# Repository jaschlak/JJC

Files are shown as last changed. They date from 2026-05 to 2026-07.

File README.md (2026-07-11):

# JJC V1

Jordan's Juggle Clubs V1 is a 3D-printing and Fusion scripting project for designing a simple juggling club around a rigid 1/2 inch dowel rod spine.

V2 is started in `JJC_v2/` as a Delphin-style, dowel-core practice club targeting a 502 mm length.

V3 is started in `JJC_v3/` as a hollow-body revision focused on lowering the estimated center of rotation compared with V2.

The printed club version folders, `JJC_v1/`, `JJC_v2/`, and `JJC_v3/`, are mechanical prototypes. They intentionally have no LEDs, microcontrollers, batteries, or diffusers.

Electronics prototyping is tracked separately in `electronics/`. Its `v1/` folder means electronics prototype v1, not printed club V1. It starts with ESP32 and WS2812B LED bench tests before any final club integration.

## Design Direction

- Main structure uses a 1/2 inch dowel rod.
- Printed parts fit around or onto the dowel.
- Most printed parts are expected to be TPU.
- The club will be designed in sections because the printer build volume is limited.
- Each part gets a numbered resource spec and, when useful, a matching Fusion script.

## Balance Estimates

Center of rotation is documented as the estimated balance point along the club axis, measured from the knob end.

```text
V1 prototype estimate: 209.1 mm from knob, 50.6% of 413 mm prototype length
V2 estimate: 272.1 mm from knob, 54.2% of 502 mm length
V3 target: 255-265 mm from knob, 51-53% of 502 mm length
V3 estimate: 260.6 mm from knob, 51.9% of 502 mm length
```

These are calculated estimates using documented geometry and material density assumptions. The real value should be checked by balancing the assembled club on a pencil or round rod.

## Printer

Current printer:

```text
Creality Ender 3 V3 SE
Build volume: 220 x 220 x 250 mm
Direct extruder: suitable for TPU
```

TPU should be printed slower than the advertised maximum printer speed.

## Folder Layout

```text
Resources/
  0_parts_list.md
  1_dowel_rod_spec.md
  2_dowel_centering_ring_spec.md
  3_handle_sleeve_spec.md
  4_knob_cap_spec.md
  Images/

Fusion/
  JJCv1_1_dowel_rod/
  JJCv1_2_dowel_centering_ring/
  JJCv1_3_handle_sleeve/
  JJCv1_4_knob cap/
  JJCv1_9_full_club_assembly/

../electronics/
  README.md
  v1/
    README.md
    parts_list.md
    assembly_guide.md
    esp32_programming.md
```

## Current Parts

### 1. Dowel Rod

The rigid spine of the club.

```text
1/2 inch = 12.7 mm
```

There is a Fusion script for creating the dowel rod as its own reference part.

Measure the actual dowel before finalizing printed fit dimensions.

### 2. Dowel Centering Ring

A washer-like part that slides over the dowel and helps keep it centered inside the future hollow club body.

### 3. Handle Sleeve

A hollow TPU grip sleeve that slides over the dowel.

### 4. Knob Cap

A TPU end cap with a blind socket for the dowel. This forms the rounded handle-end bumper.

### 9. Full Club Assembly

A Fusion assembly script creates the dowel rod, handle sleeve, knob cap, body-to-handle collar, lower body shell, upper body shell, and nose cap as separate components in one design.

## Fusion Workflow

Fusion scripts must be run from inside Autodesk Fusion, not from normal desktop Python.

To run a script:

1. Open Fusion.
2. Create or open a design.
3. Go to **Utilities > Add-Ins > Scripts and Add-Ins**.
4. Add the relevant script folder if it is not already listed.
5. Select the script.
6. Click **Run**.

Do not run the script with the normal VS Code Python play button. That will fail because regular Python cannot import Fusion's `adsk` module.

## Debugging

Use Fusion's VS Code attach workflow.

The Fusion-generated script folders may include:

```text
.vscode/launch.json
```

Use the attach configuration, usually connecting to:

```text
localhost:9000
```

If VS Code reports connection refused, Fusion's debug listener is not running.

## Units

Fusion's Python API uses centimeters internally.

The scripts use millimeter variables and convert them with:

```python
def mm_to_cm(value_mm):
    return value_mm / 10.0
```

## Notes

- Keep resource specs and Fusion scripts numbered to match the parts list.
- Prefer small test parts before large shell sections.
- Update specs when measurements from real printed parts show the fit needs adjustment.

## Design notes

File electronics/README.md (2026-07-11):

# Electronics Development

This folder contains electronics prototyping and versioning documentation for the JJC club project.

## Goal

- Prototype LED control and driver electronics for future club versions
- Support WS2812B / NeoPixel-style addressable LEDs
- Keep early tests on the bench before integrating electronics into a printed club
- Provide a path toward motion sensing, timing, club sync, and app control

## Structure

- `v1/` - initial ESP32 and LED prototype docs
- `v2/` - planned future refinements and physical integration notes
- `README.md` - overview and compatibility notes

## Recommended Docs

- `v1/parts_list.md` - ESP32-based parts and prototyping items
- `v1/assembly_guide.md` - step-by-step ESP32 and LED assembly guide
- `v1/esp32_programming.md` - Arduino IDE and MicroPython programming notes

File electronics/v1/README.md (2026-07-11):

# Electronics Prototype v1

**Compatibility:** ESP32 dev board, 5V WS2812B-style addressable LEDs, and bench power testing.

## Focus

- Learn how to solder and wire NeoPixel-style LEDs
- Control LED colors from code using a small embedded board
- Prototype basic light behavior before designing final club integration
- Start with electronics similar to what the final product may use

## Suggested Parts

1. **Microcontroller**
   - Preferred: ESP32 dev board with USB-C if possible
   - Reason: built-in Wi-Fi/Bluetooth, more memory, and a stronger path to future app control or sync features
2. **LED strip**
   - WS2812B NeoPixel-style strip, individually addressable RGB LEDs
   - Choose a short section for prototyping, such as 8-16 LEDs
3. **Power**
   - 5V USB power supply or 5V bench supply
   - For ESP32, power the board from 5V VIN or a regulated 5V source and share ground with the LEDs
4. **Reliability parts**
   - 1000 uF electrolytic capacitor across LED 5V and GND
   - 330 ohm resistor in series with the LED data line
   - 3.3V-to-5V logic level shifter for the WS2812B data line
5. **Assembly supplies**
   - Soldering iron and solder
   - Heat shrink tubing
   - Silicone wire or jumper wires

## Purchase Links

- Microcontroller: https://www.amazon.com/dp/B0FRXZD6VC
- LED strip: https://www.amazon.com/dp/B097BWJGYK
- 5V power: https://www.amazon.com/s?k=5v+usb+power+supply

## Power Safety

Do not power a full 300-LED strip at high brightness from the ESP32 or a normal computer USB port.

For first tests:

- Use only a short LED section.
- Keep brightness low in software.
- Use a 5V supply sized for the number of LEDs connected.
- Always connect ESP32 GND and LED power supply GND together.

## Notes

- Keep the first prototype simple: code-driven colors only.
- The controller should be small enough to fit inside a club later.
- Later versions can add motion sensing, timing, sync, and button control.

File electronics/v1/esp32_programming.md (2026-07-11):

# ESP32 Programming Guide

This guide assumes you will use the Arduino IDE, Arduino-compatible tooling, or MicroPython to program the ESP32.

## 1. Install ESP32 Arduino Support

1. Open the Arduino IDE.
2. Go to `File > Preferences`.
3. In `Additional Boards Manager URLs`, add:
   - `https://espressif.github.io/arduino-esp32/package_esp32_index.json`
4. Open `Tools > Board > Boards Manager`.
5. Search for `esp32` and install the `esp32` package by Espressif.

## 2. Choose The Board

1. Go to `Tools > Board` and choose your ESP32 model.
2. Set the correct port under `Tools > Port`.
3. Set `Upload Speed` to `921600` or `115200` if needed.

## 3. Install FastLED

1. Open `Sketch > Include Library > Manage Libraries`.
2. Search for `FastLED`.
3. Install the FastLED library by Daniel Garcia and Mark Kriegsman.

## 4. Basic ESP32 Test Sketch

Create a new sketch and paste:

```cpp
#include <FastLED.h>

#define LED_PIN 5
#define NUM_LEDS 12
#define BRIGHTNESS 80
#define LED_TYPE WS2812B
#define COLOR_ORDER GRB

CRGB leds[NUM_LEDS];

void setup() {
  FastLED.addLeds<LED_TYPE, LED_PIN, COLOR_ORDER>(leds, NUM_LEDS).setCorrection(TypicalLEDStrip);
  FastLED.setBrightness(BRIGHTNESS);
}

void loop() {
  fill_rainbow(leds, NUM_LEDS, millis() / 20, 7);
  FastLED.show();
  delay(20);
}
```

- `LED_PIN` should match the GPIO pin wired to the data line.
- `NUM_LEDS` should match the number of LEDs connected.
- Keep `BRIGHTNESS` low for USB-powered tests.

## 5. Uploading The Sketch

1. Connect the ESP32 to your PC with USB.
2. Select the correct board and COM port.
3. Click upload.
4. Watch the output console for `Connecting...` and `Done uploading`.

## 6. Troubleshooting

If the LEDs do not light:

- Verify the strip is powered with 5V.
- Confirm ground is shared with ESP32.
- Confirm `LED_PIN` matches the chosen GPIO.
- Confirm strip data direction is correct.
- Try a lower LED count and lower brightness.
- Add the level shifter, 330 ohm resistor, and 1000 uF capacitor if they are not already installed.

## 7. Color Cycle With Button Support

Use this script after the basic test works. GPIO 14 is used for the button to avoid ESP32 boot strap pins such as GPIO 0.

```cpp
#include <FastLED.h>

#define LED_PIN 5
#define NUM_LEDS 12
#define BRIGHTNESS 80
#define BUTTON_PIN 14
#define LED_TYPE WS2812B
#define COLOR_ORDER GRB

CRGB leds[NUM_LEDS];
int currentMode = 0;

void setup() {
  pinMode(BUTTON_PIN, INPUT_PULLUP);
  FastLED.addLeds<LED_TYPE, LED_PIN, COLOR_ORDER>(leds, NUM_LEDS).setCorrection(TypicalLEDStrip);
  FastLED.setBrightness(BRIGHTNESS);
}

void loop() {
  static bool previousPressed = false;
  bool pressed = digitalRead(BUTTON_PIN) == LOW;

  if (pressed && !previousPressed) {
    currentMode = (currentMode + 1) % 3;
    delay(40);
  }
  previousPressed = pressed;

  switch (currentMode) {
    case 0:
      rainbowCycle();
      break;
    case 1:
      meteorRain(CRGB::Blue);
      break;
    case 2:
      colorWipe(CRGB::Red);
      break;
  }

  FastLED.show();
  delay(20);
}

void rainbowCycle() {
  fill_rainbow(leds, NUM_LEDS, millis() / 20, 7);
}

void meteorRain(const CRGB& color) {
  fadeToBlackBy(leds, NUM_LEDS, 64);
  int index = (millis() / 40) % NUM_LEDS;
  leds[index] = color;
}

void colorWipe(const CRGB& color) {
  static int index = 0;
  fadeToBlackBy(leds, NUM_LEDS, 24);
  leds[index] = color;
  index = (index + 1) % NUM_LEDS;
}
```

## 8. MicroPython Quickstart

If you prefer MicroPython, the ESP32 runs it well.

### Flash MicroPython Firmware

1. Download the current stable MicroPython ESP32 `.bin` from https://micropython.org/download/esp32/.
2. Install `esptool.py`:

```bash
python -m pip install esptool
```

3. Erase the board and write the firmware, replacing the COM port and file name:

```bash
esptool.py --port COM3 erase_flash
esptool.py --chip esp32 --port COM3 write_flash -z 0x1000 esp32-202*.bin
```

### Upload A NeoPixel Test

Install `ampy`:

```bash
python -m pip install adafruit-ampy
```

Create a file named `main.py` with this content:

```python
import machine
import neopixel
import time

NUM_LEDS = 12
DATA_PIN = 5
BRIGHTNESS = 0.25

pin = machine.Pin(DATA_PIN, machine.Pin.OUT)
np = neopixel.NeoPixel(pin, NUM_LEDS)

def scale(color):
    return tuple(int(channel * BRIGHTNESS) for channel in color)

def wheel(pos):
    pos = 255 - pos
    if pos < 85:
        return scale((255 - pos * 3, 0, pos * 3))
    if pos < 170:
        pos -= 85
        return scale((0, pos * 3, 255 - pos * 3))
    pos -= 170
    return scale((pos * 3, 255 - pos * 3, 0))

def rainbow_cycle():
    for j in range(255):
        for i in range(NUM_LEDS):
            pixel_index = (i * 256 // NUM_LEDS) + j
            np[i] = wheel(pixel_index & 255)
        np.write()
        time.sleep_ms(20)

while True:
    rainbow_cycle()
```

Upload it with `ampy`:

```bash
ampy --port COM3 put main.py
```

When the board boots it will run `main.py` and the LEDs should cycle.

## Notes

- Use a common ground between the ESP32 and the LED strip.
- If the strip is powered from 5V, use a logic level shifter for maximum reliability.
- Keep brightness low and use only a short LED section for USB-powered tests.
- For interactive REPL, use PuTTY on Windows or `screen` on Linux/macOS at 115200 baud.

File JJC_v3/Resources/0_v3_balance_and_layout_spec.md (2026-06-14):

# JJC V3 Balance And Layout Spec

## Goal

Create a lighter hollow-body club that does not feel top-heavy in rotation.

V3 keeps the V2 overall length and handle layout, but changes the two body shells to hollow printed shells with an overlapping slip joint.

Reference diagram:

```text
Resources/Images/JJC_v3_hollow_body_concept.svg
```

## Balance Target

There is not a single official center-of-rotation standard for juggling clubs. For this project, use this practical target:

```text
Target balance point: 255-265 mm from knob end
Target balance ratio: 51-53% of total length from knob end
Overall length: 502 mm
```

This keeps the center of rotation slightly above the midpoint, near the body, but not close to the nose.

## V2 Estimate

Using the V2 dimensions and estimated material densities:

```text
Estimated V2 mass: 295.5 g
Estimated V2 balance point: 272.1 mm from knob end
Estimated V2 balance ratio: 54.2% of total length
```

That is higher than the V3 target.

## V3 Estimate

Using hollow body shells, no full-length body dowel sleeves, and the wall thicknesses below:

```text
Part 5 lower body wall thickness: 2.0 mm
Part 6 upper body wall thickness: 1.6 mm
Estimated V3 mass: 266.1 g
Estimated V3 balance point: 260.6 mm from knob end
Estimated V3 balance ratio: 51.9% of total length
```

The estimate assumes:

```text
Hardwood dowel density: 0.70 g/cm^3
TPU/plastic density: 1.20 g/cm^3
Dowel diameter: 12.7 mm
Dowel length: 502 mm
V2 knob, handle, collar, and nose cap dimensions unchanged
Part 5 and Part 6 are hollow shells
Part 5 has a closed bottom plate
Part 6 has a closed top plate
Part 5/6 joint uses a 10 mm overlap
```

## V3 Axial Layout

```text
Part 2 knob cap: 0-28 mm
Part 3 handle sleeve: 28-213 mm
Part 4 handle-to-body collar: 213-233 mm
Part 5 lower hollow body shell: 233-348 mm
Part 6 upper hollow body shell: 348-490 mm
Part 7 nose cap: 490-502 mm
```

## Tuning Rules

After printing one assembled club, balance it on a pencil or round rod and measure from the knob end.

```text
If balance is above 265 mm:
- reduce Part 6 wall thickness by 0.2 mm
- reduce Part 6 top plate thickness by 0.5-1.0 mm
- or add weight near the knob/handle

If balance is below 255 mm:
- increase Part 6 wall thickness by 0.2 mm
- increase Part 6 top plate thickness by 0.5 mm
- or reduce Part 5 wall thickness by 0.2 mm
```

Do not tune balance by making the nose cap heavy unless needed for durability. Nose mass has a large effect on spin feel.

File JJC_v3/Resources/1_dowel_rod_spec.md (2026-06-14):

# V3 Dowel Rod Spec

## Purpose

The dowel rod is the rigid center spine for the JJC V3 hollow-body club.

Reference diagram:

```text
Resources/Images/1_dowel_rod_fit.svg
```

## Geometry

```text
Diameter: 12.7 mm
Length: 502 mm
Material: hardwood dowel
```

Printed dowel holes and sockets use a starting clearance diameter of 13.2 mm.

## Balance Role

The dowel is modeled as a 44.5 g hardwood spine with its center at 251 mm from the knob end. It stabilizes the club and keeps the baseline mass close to the middle of the 502 mm length.

## Notes

Measure the actual dowel before finalizing socket clearances.

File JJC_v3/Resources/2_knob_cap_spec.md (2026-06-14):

# V3 Knob Cap Spec

## Purpose

The knob cap protects the handle end of the dowel and creates the club's catching stop.

V3 keeps the V2 knob geometry because it helps counterbalance the upper body.

Reference diagram:

```text
Resources/Images/2_knob_cap_fit.svg
```

## Geometry

```text
Outer diameter: 33 mm
Height: 28 mm
Dowel socket diameter: 13.2 mm
Socket depth: 22 mm
Closed end thickness: 6 mm
#6 wood screw pilot hole: 2.9 mm through the closed end
Screw outer-clearance chamfer: 10.0 mm outside diameter to 2.9 mm pilot diameter
Screw-side outside shape: lofted asymmetric-style soft end based on 18.0 mm / 3.0 mm fillet target, clamped to preserve screw-seat wall
Socket-side outside shape: lofted asymmetric-style soft end based on 9.0 mm / 10.0 mm fillet target, clamped to preserve socket wall
```

## Balance Role

The knob cap is useful lower mass. Do not reduce it until the printed club is balanced and weighed.

Estimated contribution:

```text
Mass: 25.1 g
Center: 13.6 mm from knob end
```

## Print Orientation

Print closed end down, socket opening up.

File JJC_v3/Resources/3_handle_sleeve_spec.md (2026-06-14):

# V3 Handle Sleeve Spec

## Purpose

The handle sleeve creates the long grip around the dowel.

V3 keeps the V2 handle sleeve geometry.

Reference diagram:

```text
Resources/Images/3_handle_sleeve_fit.svg
```

## Geometry

```text
Knob-side outer diameter: 18.2 mm
Grip/collar-side outer diameter: 24 mm
Inner diameter: 13.2 mm
Length: 185 mm
Side profile: single straight taper over full length
```

## Balance Role

The handle is the main lower-mass region used to keep the club from feeling nose-heavy.

Estimated contribution:

```text
Mass: 47.7 g
Center: 134.3 mm from knob end
```

## Print Orientation

Print vertically if TPU is stable enough. If the print wobbles, split the handle into two shorter sleeve sections.

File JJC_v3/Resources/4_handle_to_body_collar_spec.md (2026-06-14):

# V3 Handle-to-Body Collar Spec

## Purpose

The collar transitions from the slim handle to the hollow body shell.

V3 keeps the V2 collar geometry so the handle/body layout stays compatible.

Reference diagram:

```text
Resources/Images/4_handle_to_body_collar_fit.svg
```

## Geometry

```text
Handle-side outer diameter: 24 mm
Body-side outer diameter: 42 mm
Inner diameter: 13.2 mm
Height: 20 mm
Side profile: straight taper
```

## Balance Role

The collar sits close to the V3 target balance region and is not a major tuning part.

Estimated contribution:

```text
Mass: 17.8 g
Center: 225.1 mm from knob end
```

## Print Orientation

Print either end down. Body-side down gives the larger bed contact area.

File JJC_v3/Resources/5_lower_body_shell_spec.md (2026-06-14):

# V3 Lower Hollow Body Shell Spec

## Purpose

The lower body shell forms the lower half of the hollow club body. It starts at the handle-to-body collar and expands to the widest body section.

It has a closed bottom, an open top, and a male slip-joint lip that slides into Part 6.

Reference diagram:

```text
Resources/Images/5_lower_body_shell_fit.svg
```

## Geometry

```text
Start Z: 233 mm
End Z: 348 mm
Height: 115 mm
Start outer diameter: 42 mm
Belly outer diameter: 70 mm
Top outer diameter: 78 mm
Wall thickness: 2.0 mm
Internal cavity diameter at bottom: 38.0 mm
Internal cavity diameter at belly: 66.0 mm
Internal cavity diameter at top before slip lip: 74.0 mm
Bottom plate thickness: 4 mm
Bottom dowel clearance hole: 13.2 mm
Top: open
Male slip lip height: 10 mm
Male slip lip outer diameter: 74.0 mm
Male slip lip wall thickness: 2.0 mm
Male slip lip inner diameter: 70.0 mm
Top edge chamfer: 0.6 mm
```

The lower wall is intentionally thicker than the upper wall. It moves mass downward relative to the upper shell and helps keep the finished club balance near the V3 target.

## Hollow Interior

This part is a hollow shell, not a solid body.

```text
Main body wall: annular 2.0 mm shell
Interior cavity: open above the 4 mm bottom plate
Bottom closure: 4 mm plate with only the 13.2 mm dowel clearance hole
Top opening through slip lip: 70.0 mm ID
Full-length center sleeve: none
Infill inside body cavity: none intended
```

In Fusion, the main body should be made as an outer solid loft followed by an explicit internal cavity loft cut. This avoids export/import ambiguity where another CAD program may interpret an annular loft as filled.

## Joint To Part 6

```text
Part 5 male lip OD: 74.0 mm
Part 6 receiving socket ID: 74.4 mm
Diametral clearance: 0.4 mm
Radial clearance: 0.2 mm per side
Overlap depth: 10 mm
Part 5 male lip ID: 70.0 mm
Part 6 stabilizing insert OD: 69.4 mm
Part 6 stabilizing insert ID: 64.4 mm
Insert diametral clearance inside Part 5 lip: 0.6 mm
```

This should be a slide fit, not a press fit. Part 6 now stabilizes the joint with a straight thickened hollow insert that slides into the open center of the Part 5 lip. If the printer makes TPU oversized, reduce the Part 6 insert OD slightly.

## Balance Role

Estimated contribution:

```text
Lower shell walls: 44.0 g combined
Lower bottom plate: 5.0 g
Lower male slip lip: 5.4 g
```

The 2.0 mm wall is part of the balance plan. Do not reduce it until a printed club has been weighed and balanced.

## Print Orientation

Print bottom down.

```text
Closed bottom on the bed
Open top upward
Slip lip printed at the top
```

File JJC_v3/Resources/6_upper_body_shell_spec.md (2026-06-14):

# V3 Upper Hollow Body Shell Spec

## Purpose

The upper body shell forms the upper half of the hollow club body. It receives the Part 5 slip lip at the bottom and closes the body near the nose.

It has a receiving slip socket, an insert that slides into Part 5, a minimal wall-supported connector ramp, and a closed top with a dowel clearance hole.

Reference diagram:

```text
Resources/Images/6_upper_body_shell_fit.svg
```

## Geometry

```text
Start Z: 348 mm
End Z: 490 mm
Height: 142 mm
Start outer diameter: 78 mm
Belly outer diameter: 66 mm
Top outer diameter: 40 mm
Wall thickness: 1.6 mm
Internal cavity diameter at bottom before socket: 74.8 mm
Internal cavity diameter at belly: 62.8 mm
Internal cavity diameter near top: 36.8 mm
Bottom: mostly open around the Part 5 insert
Insert hub height inside Part 6: 2 mm
Part 5 insert depth: 10 mm
Part 5 insert outer diameter: 69.4 mm
Part 5 insert inner diameter: 64.4 mm
Thickened insert wall thickness: 2.5 mm
Insert-to-shell main flare height: 7 mm
Insert-to-shell wall blend height: 10 mm
Receiving socket depth: 10 mm
Receiving socket inner diameter: 74.4 mm
Receiving socket outer diameter: 76.4 mm
Receiving socket wall thickness: 1.0 mm minimum
Top plate thickness: 3 mm
Top dowel clearance hole: 13.2 mm
Bottom edge chamfer: 0.6 mm
```

The upper wall is thinner than the lower wall to reduce top mass and keep the balance point out of the nose-heavy range.

## Hollow Interior

This part is a hollow shell, not a solid body.

```text
Main body wall: annular 1.6 mm shell
Interior cavity: open around the lower insert until the 3 mm top plate
Bottom receiving opening: 74.4 mm ID at the socket around the insert
Lower closure: none across the full body diameter
Part 5 stabilizing insert: straight thickened hollow sleeve, 69.4 mm OD x 64.4 mm ID x 10 mm deep, continuing 2 mm into Part 6 as a hub
Insert-to-shell flare: short conical sleeve from the insert hub toward the normal Part 6 shell wall, followed by a small outer-wall blend profile so the sleeve does not end as a blunt flat ring
Bottom receiving socket: reinforced by a full annular wall from 76.4 mm OD to 74.4 mm ID for improved shell rigidity and better fit to Part 5
Top closure: 3 mm plate with only the 13.2 mm dowel clearance hole; interior top edge includes a 1 mm sloped transition between the top disk and outer wall for printability
Full-length center sleeve: none
Infill inside body cavity: none intended
```

In Fusion, the main body should be made as an outer solid loft followed by an explicit internal cavity loft cut. This avoids export/import ambiguity where another CAD program may interpret an annular loft as filled.

## Joint To Part 5

```text
Part 5 male lip OD: 74.0 mm
Part 6 receiving socket ID: 74.4 mm
Diametral clearance: 0.4 mm
Radial clearance: 0.2 mm per side
Overlap depth: 10 mm
Part 6 stabilizing insert OD: 69.4 mm
Part 6 stabilizing insert ID: 64.4 mm
Part 5 male lip ID: 70.0 mm
Insert diametral clearance: 0.6 mm
```

The joint is meant to locate the shells and resist side movement. Part 6's straight 69.4 mm hollow insert reaches into Part 5's 70.0 mm lip opening. The thickened insert and shorter flared sleeve hub add joint stiffness without filling the lower end of Part 6 with a broad disk. Bond the overlap with flexible adhesive if the shell should be permanent.

## Balance Role

Estimated contribution:

```text
Upper shell walls: 33.8 g combined
Upper top plate: 3.6 g
Upper receiving socket wall: 2.3 g
Lower insert and flared sleeve: adds joint stiffness with much less mass than a full stabilizing disk
```

The 1.6 mm wall is the main V3 balance change. Increasing this wall moves the center of rotation upward; decreasing it moves the center downward.

## Print Orientation

Print top down.

```text
Closed top on the bed
Straight thickened hollow insert printed near the top of the print
The main flare reaches its shoulder 5 mm above the insert hub, then blends into the wall over the next 3 mm to reduce the abrupt shelf at the shell wall
```

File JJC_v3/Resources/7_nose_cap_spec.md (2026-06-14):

# V3 Nose Cap Spec

## Purpose

The nose cap protects the top end of the club and closes the upper body.

V3 keeps the compact V2 nose cap geometry to avoid adding unnecessary top mass.

Reference diagram:

```text
Resources/Images/7_nose_cap_fit.svg
```

## Geometry

```text
Socket-side outer diameter: 40 mm
Screw-side face diameter: 22 mm
Height: 12 mm
Dowel socket diameter: 13.2 mm
Socket depth: 7 mm
Closed end thickness: 5 mm
Screw clearance hole: 3.2 mm
Screw head chamfer: 10.0 mm diameter x 2.0 mm deep
Socket-side outside shape: 40 mm shoulder matching Part 6 nose-side outer diameter
Screw-side outside shape: short taper to a compact 22 mm end face
```

The screw hole is centered on the club axis. It allows a small wood screw to pass through the TPU cap and bite into the end of the dowel.

## Balance Role

The nose cap has a large effect on spin feel because it is far from the knob. Keep this part compact unless impact durability requires more material.

Estimated contribution:

```text
Mass: 10.0 g
Center: 495.0 mm from knob end
```

## Print Orientation

Print closed end down, socket opening up.

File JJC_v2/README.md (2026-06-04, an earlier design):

# JJC V2

JJC V2 is a Delphin-style juggling club prototype: a long, light, dowel-core club intended to be good enough for actual juggling practice.

This is not a copy of Henry's geometry or branding. It uses the same broad category: a light composite club with a rigid center dowel, long handle, slim body, and replaceable printed end parts.

## Design Targets

| Feature | Target |
| --- | ---: |
| Overall length | 520 mm |
| Target finished weight | 200-220 g |
| Core | 12.7 mm hardwood dowel |
| Handle outside diameter | 24 mm |
| Maximum body outside diameter | 78 mm |
| Material | TPU printed parts around wood dowel |
| Printer | Creality Ender 3 V3 SE |

## Parts

| Item | Part | Length |
| ---: | --- | ---: |
| 1 | Dowel rod | 520 mm |
| 2 | Knob cap | 28 mm |
| 3 | Handle sleeve | 185 mm |
| 4 | Handle-to-body collar | 20 mm |
| 5 | Lower body shell | 115 mm |
| 6 | Upper body shell | 142 mm |
| 7 | Nose cap | 30 mm |

## Folder Layout

```text
Resources/
  0_v2_delphin_style_spec.md
  1_dowel_rod_spec.md
  2_knob_cap_spec.md
  3_handle_sleeve_spec.md
  4_handle_to_body_collar_spec.md
  5_lower_body_shell_spec.md
  6_upper_body_shell_spec.md
  7_nose_cap_spec.md
  Images/

Fusion/
  JJCv2_shared/
  JJCv2_0_delphin_style_club/
  JJCv2_1_dowel_rod/
  JJCv2_2_knob_cap/
  JJCv2_3_handle_sleeve/
  JJCv2_4_handle_to_body_collar/
  JJCv2_5_lower_body_shell/
  JJCv2_6_upper_body_shell/
  JJCv2_7_nose_cap/
```

## Fusion Scripts

The individual scripts and the full assembly script all import their geometry from:

```text
JJC_v2/Fusion/JJCv2_shared/jjc_v2_parts.py
```

Change dimensions and part geometry there first. The standalone scripts and assembly script will then use the same source.

Run the full assembly script from inside Autodesk Fusion:

```text
JJC_v2/Fusion/JJCv2_0_delphin_style_club
```

The full assembly script creates each club part as a separate Fusion component. Run it in a Hybrid Design or Assembly Design. A normal Part Design document only allows one component and will reject the assembly.

Run individual part scripts when preparing printable part files:

```text
JJC_v2/Fusion/JJCv2_1_dowel_rod
JJC_v2/Fusion/JJCv2_2_knob_cap
JJC_v2/Fusion/JJCv2_3_handle_sleeve
JJC_v2/Fusion/JJCv2_4_handle_to_body_collar
JJC_v2/Fusion/JJCv2_5_lower_body_shell
JJC_v2/Fusion/JJCv2_6_upper_body_shell
JJC_v2/Fusion/JJCv2_7_nose_cap
```

If you later want true Fusion components and joints, create a Hybrid Design or Assembly Design first and the scripts can be adapted for that workflow.

## Print Strategy

The full club is too long to print as one object. Print the TPU parts separately and assemble them onto the dowel:

1. Print a short fit test for the dowel hole before printing full parts.
2. Print the handle sleeve upright if the TPU is stable.
3. Print the body shells wide side down.
4. Use low infill where there is actual internal volume, but expect thin walls to print mostly as perimeters.
5. Weigh the finished club and tune shell wall thickness or cap thickness before printing a matched set.

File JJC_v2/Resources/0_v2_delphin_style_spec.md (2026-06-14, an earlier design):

# JJC V2 Delphin-Style Club Spec

## Goal

Create a light, juggleable, Delphin-style club around a 1/2 inch hardwood dowel.

The target is not to copy Henry's Delphin dimensions exactly. The useful reference points are:

- long training club length around 51 cm
- finished weight around 205 g
- rigid wood spine
- long handle
- slim, rounded body

## Target Geometry

```text
Overall length: 502 mm
Dowel diameter: 12.7 mm
Dowel clearance holes: 13.2 mm
Handle OD: 24 mm
Max body OD: 78 mm
Nose OD: 40 mm
Knob cap #6 screw pilot: 2.9 mm
Knob cap screw outer-clearance chamfer: 10.0 mm outside diameter to 2.9 mm pilot diameter
Nose cap screw clearance: 3.2 mm
Nose cap socket-side OD: 40 mm to match Part 6
Nose cap screw-side face diameter: 22 mm
Nose cap height: 12 mm
Nose cap screw head chamfer: 10.0 mm diameter x 2.0 mm deep
```

## Axial Layout

| Item | Part | Start Z | Length | End Z |
| ---: | --- | ---: | ---: | ---: |
| 2 | Knob cap | 0 mm | 28 mm | 28 mm |
| 3 | Handle sleeve | 28 mm | 185 mm | 213 mm |
| 4 | Handle-to-body collar | 213 mm | 20 mm | 233 mm |
| 5 | Lower body shell | 233 mm | 115 mm | 348 mm |
| 6 | Upper body shell | 348 mm | 142 mm | 490 mm |
| 7 | Nose cap | 490 mm | 12 mm | 502 mm |

The printed parts stack to 502 mm. The caps have blind sockets, so the dowel does not need to run through every last millimeter of printed bumper material.

## Estimated Balance

Using the documented V2 dimensions and estimated material densities:

```text
Hardwood dowel density assumption: 0.70 g/cm^3
TPU/plastic density assumption: 1.20 g/cm^3
Estimated V2 mass: 295.5 g
Estimated V2 balance point: 272.1 mm from knob end
Estimated V2 balance ratio: 54.2% of total length
```

This estimate is the club's center of mass along the dowel axis. It should be checked by balancing a printed assembly on a pencil or round rod.

## Body Shape

The V2 body uses a long slim Delphin-style profile:

```text
Collar end: 42 mm OD
Widest point: 78 mm OD
Nose end: 40 mm OD
Body shell wall: 1.2 mm
Internal sleeve OD: 17 mm
Internal sleeve ID: 13.2 mm
Bulkheads: 4 mm at shell ends
```

## Weight Tuning

The first prototype should be weighed after assembly. To reduce weight:

- reduce body shell wall from 1.2 mm to 1.0 mm
- reduce sleeve OD from 17 mm to 16 mm
- reduce cap closed-end thickness

To increase durability:

- increase body shell wall to 1.6 mm
- use 3 perimeters in the slicer
- increase bulkhead height from 4 mm to 6 mm

## Slicer Starting Point

Recommended Simplify3D starting profile:

```text
Layer height: 0.24-0.30 mm
Perimeters: 3
Infill: 10-15%
Top/bottom layers: 3
TPU speed: 25-35 mm/s if feeding reliably
```

Thin walls and rings may still print mostly as perimeters/gap fill. That is expected.

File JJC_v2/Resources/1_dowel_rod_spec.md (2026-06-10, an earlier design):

# V2 Dowel Rod Spec

## Purpose

The dowel rod is the rigid center spine for the JJC V2 Delphin-style club.

Reference diagram:

```text
Resources/Images/1_dowel_rod_fit.svg
```

## Geometry

```text
Diameter: 12.7 mm
Length: 502 mm
Material: hardwood dowel
```

## Notes

Measure the actual dowel before finalizing printed socket clearances. Printed TPU parts use a starting hole/socket diameter of 13.2 mm.

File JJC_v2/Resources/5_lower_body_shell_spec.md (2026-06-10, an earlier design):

# V2 Lower Body Shell Spec

## Purpose

The lower body shell starts at the collar and expands into the widest part of the club body.

Reference diagram:

```text
Resources/Images/5_lower_body_shell_fit.svg
```

## Geometry

```text
Start outer diameter: 42 mm
Belly outer diameter: 70 mm
End outer diameter: 78 mm
Height: 115 mm
Wall thickness: 1.2 mm
Dowel sleeve OD: 17 mm
Dowel sleeve ID: 13.2 mm
Bulkhead height: 4 mm
```

The 13.2 mm sleeve ID is an open through-bore for the 1/2 inch dowel rod.

## Print Orientation

Print standing upright with the 42 mm side on the bed unless bed adhesion requires a brim.

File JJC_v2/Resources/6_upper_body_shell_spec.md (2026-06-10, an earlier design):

# V2 Upper Body Shell Spec

## Purpose

The upper body shell continues from the widest body section and narrows toward the nose cap.

Reference diagram:

```text
Resources/Images/6_upper_body_shell_fit.svg
```

## Geometry

```text
Start outer diameter: 78 mm
Belly outer diameter: 66 mm
End outer diameter: 40 mm
Height: 142 mm
Wall thickness: 1.2 mm
Dowel sleeve OD: 17 mm
Dowel sleeve ID: 13.2 mm
Bulkhead height: 4 mm
```

## Print Orientation

Print standing upright with the 78 mm side on the bed.

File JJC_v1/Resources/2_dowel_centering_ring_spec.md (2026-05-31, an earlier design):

# Dowel Centering Ring Spec

## Purpose

The dowel centering ring keeps the dowel rod aligned with the center axis of the JJC V1 juggling club body. It is the first printed test part for Jordan's Juggle Clubs.

Design status note:

Parts 6 and 7 now include built-in dowel sleeves and internal bulkheads, so they do not require this separate centering ring. Item 2 remains useful as a dowel-fit test part and may still be used later as an optional spacer or alignment part.

Reference diagram:

```text
Resources/Images/2_dowel_centering_ring_fit.svg
```

## Part Function

- Slides over the dowel rod
- Fits inside a future hollow club body shell
- Holds the dowel near the center of the shell
- Provides a simple test for Fusion scripting, print tolerance, and TPU fit

## Version 1 Geometry

Basic shape: washer-like ring

Suggested starting dimensions:

| Feature | Value | Notes |
| --- | ---: | --- |
| Outer diameter | 35 mm | Placeholder until body shell diameter is chosen |
| Inner diameter | Dowel diameter + clearance | Measure the actual dowel before finalizing |
| Thickness | 6 mm | Tall enough to guide the dowel without taking long to print |
| Edge treatment | Small chamfer or fillet | Helps insertion and reduces sharp TPU edges |

## Dowel Fit

The inner diameter should be larger than the measured dowel diameter.

Suggested starting clearance:

| Material | Clearance |
| --- | ---: |
| TPU flexible slip fit | +0.3 mm to +0.6 mm |
| PETG/PLA slip fit | +0.2 mm to +0.4 mm |

Example:

If the dowel measures 12.7 mm:

```text
inner diameter = 13.2 mm
```

This gives 0.5 mm total clearance.

## Outer Fit

The outer diameter should eventually match the inside diameter of the club body shell.

For the first test print, use:

```text
outer diameter = 35 mm
```

Once the body shell is designed, update this to:

```text
outer diameter = shell inner diameter - clearance
```

Suggested shell clearance:

```text
0.3 mm to 0.8 mm total clearance
```

TPU can tolerate a tighter fit than rigid filament, but too tight may make assembly difficult.

## Print Material

Preferred first material:

```text
TPU
```

Reasons:

- matches the expected club material
- tests flexibility around the dowel
- allows slight compression during assembly

Alternative:

```text
PETG
```

PETG may be useful later if the centering ring needs more stiffness.

## Print Orientation

Print flat on the bed like a washer.

Benefits:

- no supports
- simple circular perimeters
- strongest layer layout for radial compression
- fast print

## First Test Goals

The first print should answer:

- Does the ring slide onto the dowel?
- Is the fit too loose, too tight, or about right?
- Does TPU flex enough to make assembly easy?
- Does the slicer preserve the hole size accurately?
- Does the outer diameter feel reasonable for a future body shell?

## Fusion Script Parameters

Use named variables in the script:

```python
outer_diameter_mm = 35.0
dowel_diameter_mm = 12.7
dowel_clearance_mm = 0.5
ring_thickness_mm = 6.0
```

Derived value:

```python
inner_diameter_mm = dowel_diameter_mm + dowel_clearance_mm
```

Fusion API note:

```text
Fusion internal length units are centimeters.
Convert mm to cm by dividing by 10.
```

## Open Questions

- What is the actual measured dowel diameter?
- Should the ring be a loose slip fit, snug fit, or press fit?
- What should the first body shell inner diameter be?
- Should the ring eventually include cutouts to save material?
- Should the ring eventually include keyed alignment features?

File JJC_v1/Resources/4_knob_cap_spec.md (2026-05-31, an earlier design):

# Knob Cap Spec

## Purpose

The knob cap is the printed end cap at the handle end of the JJC V1 club. It protects the end of the dowel rod, gives the club a rounded handle end, and provides an impact-tolerant TPU bumper.

Reference diagram:

```text
Resources/Images/4_knob_cap_fit.svg
```

## Part Function

- Fits over the end of the 1/2 inch dowel rod
- Protects the dowel end from impacts
- Creates a rounded, larger knob at the handle end
- Helps keep the club comfortable and safer to catch

## Version 1 Geometry

Basic shape: short cylindrical cap with a blind dowel socket

Suggested starting dimensions:

| Feature | Value | Notes |
| --- | ---: | --- |
| Outer diameter | 34 mm | Larger than the handle sleeve so it acts as a stop/knob |
| Dowel socket diameter | 13.2 mm | 12.7 mm dowel plus 0.5 mm clearance |
| Cap height | 28 mm | Short first-print test |
| Socket depth | 22 mm | Leaves 6 mm of material at the closed end |
| Edge treatment | 1 mm chamfer | Reduces sharp TPU edges |

## Dowel Fit

Use the same dowel clearance as Parts 2 and 3:

```text
1/2 inch dowel = 12.7 mm
clearance = 0.5 mm
socket diameter = 13.2 mm
```

The socket is blind, so the dowel does not pass all the way through the knob cap.

## Print Material

Preferred material:

```text
TPU
```

Reasons:

- absorbs drops and impacts
- feels better in the hand than rigid plastic
- can flex slightly around the dowel

## Print Orientation

Recommended first print orientation:

```text
closed end on the bed, socket opening upward
```

This keeps the solid closed end on the XY plane and leaves the dowel socket opening upward.

## First Test Goals

The first print should answer:

- Does the socket fit the dowel?
- Is the cap too loose, too tight, or about right?
- Is 34 mm a reasonable knob diameter?
- Does the cap feel comfortable at the handle end?
- Does TPU make a good impact bumper for this shape?

## Fusion Script Parameters

Use named variables in the script:

```python
outer_diameter_mm = 34.0
dowel_diameter_mm = 12.7
dowel_clearance_mm = 0.5
cap_height_mm = 28.0
socket_depth_mm = 22.0
edge_chamfer_mm = 1.0
```

Derived value:

```python
socket_diameter_mm = dowel_diameter_mm + dowel_clearance_mm
```

Fusion API note:

```text
Fusion internal length units are centimeters.
Convert mm to cm by dividing by 10.
```

## Open Questions

- Is 34 mm a good knob diameter?
- Should the knob be more rounded in a later version?
- Should the socket be slip fit, snug fit, or glued?
- Should the cap include a mechanical retention feature later?

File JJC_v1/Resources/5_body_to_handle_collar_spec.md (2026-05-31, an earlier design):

# Body-to-Handle Collar Spec

## Purpose

The body-to-handle collar is the transition piece between the narrow handle sleeve and the wider club body. It helps define the club shape and gives the lower body shell a larger surface to connect to.

Reference diagram:

```text
Resources/Images/5_body_to_handle_collar_fit.svg
```

## Part Function

- Slides over the 1/2 inch dowel rod
- Sits above the handle sleeve
- Flares from handle diameter toward body diameter
- Provides a transition surface for the future lower body shell
- Helps test the feel of the handle-to-body shape

## Version 1 Geometry

Basic shape: tapered collar with a center dowel hole

Suggested starting dimensions:

| Feature | Value | Notes |
| --- | ---: | --- |
| Handle-side outer diameter | 24 mm | Matches the first handle sleeve outer diameter |
| Body-side outer diameter | 42 mm | First estimate for the lower club body transition; starts on the XY plane |
| Inner diameter | 13.2 mm | 12.7 mm dowel plus 0.5 mm clearance |
| Height | 35 mm | Short enough for a fast test print |
| Edge treatment | 0.75 mm chamfer | Reduces sharp TPU edges |

## Dowel Fit

Use the same dowel clearance as Parts 2, 3, and 4:

```text
1/2 inch dowel = 12.7 mm
clearance = 0.5 mm
inner diameter = 13.2 mm
```

## Fit To Nearby Parts

The handle-side diameter should align with the handle sleeve:

```text
handle sleeve outer diameter = 24 mm
collar handle-side outer diameter = 24 mm
```

The body-side diameter is a placeholder for the future lower body shell:

```text
collar body-side outer diameter = 42 mm
```

This can be adjusted after the first body shell dimensions are chosen.

## Print Material

Preferred material:

```text
TPU
```

Reasons:

- impact tolerant
- flexible enough for fitting around the dowel
- consistent with the handle sleeve and knob cap

## Print Orientation

Recommended first print orientation:

```text
standing vertically with the wider 42 mm body side on the bed
```

Benefits:

- wider base improves bed contact
- center hole prints vertically
- no support should be needed for the taper

## First Test Goals

The first print should answer:

- Does the collar slide onto the dowel?
- Does 24 mm line up well with the handle sleeve?
- Does 42 mm feel like a reasonable start for the body transition?
- Does the taper print cleanly in TPU?
- Does the part feel too tall, too short, too steep, or about right?

## Fusion Script Parameters

Use named variables in the script:

```python
handle_side_outer_diameter_mm = 24.0
body_side_outer_diameter_mm = 42.0
dowel_diameter_mm = 12.7
dowel_clearance_mm = 0.5
collar_height_mm = 35.0
edge_chamfer_mm = 0.75
```

Derived value:

```python
inner_diameter_mm = dowel_diameter_mm + dowel_clearance_mm
```

Fusion API note:

```text
Fusion internal length units are centimeters.
Convert mm to cm by dividing by 10.
```

## Open Questions

- Is 42 mm a good starting diameter for the body side?
- Should the taper be straight, curved, or stepped?
- Should this part mechanically lock to the lower body shell?
- Should the collar be bonded to the dowel or remain removable?

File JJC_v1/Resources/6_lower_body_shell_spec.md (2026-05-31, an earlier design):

# Lower Body Shell Spec

## Purpose

The lower body shell is the first hollow club-body section above the body-to-handle collar. It begins defining the larger club body shape while keeping the dowel rod as the rigid center spine.

Reference diagram:

```text
Resources/Images/6_lower_body_shell_fit.svg
```

## Part Function

- Forms the lower hollow body of the club
- Fits around the dowel rod with internal space for centering rings
- Connects conceptually to the body-to-handle collar
- Tests TPU printing of a larger hollow tapered shell

## Version 1 Geometry

Basic shape: hollow tapered tube

Suggested starting dimensions:

| Feature | Value | Notes |
| --- | ---: | --- |
| Wide outer diameter | 58 mm | Starts on the XY plane for better printing |
| Collar-side outer diameter | 42 mm | Matches the body side of Part 5 |
| Wall thickness | 2 mm | First TPU shell test |
| Height | 120 mm | Fits comfortably in the printer height |
| Dowel sleeve inner diameter | 13.2 mm | 12.7 mm dowel plus 0.5 mm clearance |
| Dowel sleeve outer diameter | 20 mm | Structural tube bonded around dowel |
| Bulkhead height | 5 mm each | Internal disks connecting sleeve to shell |
| Edge treatment | 0.5 mm chamfer | Reduces sharp TPU edges |

## Orientation

The wide 58 mm side should start on the XY plane:

```text
wide body side = Z 0 / XY plane
collar-side 42 mm opening = top
```

This prints the part wide-side down for better bed contact.

## Fit To Nearby Parts

The collar-side opening should match Part 5:

```text
Part 5 body-side outer diameter = 42 mm
Part 6 collar-side outer diameter = 42 mm
```

This version includes an integrated dowel sleeve and two internal bulkheads, so it is more than a loose outer shell.

## Structural Features

Part 6 now has:

- a center sleeve around the dowel
- a lower bulkhead near the XY plane
- an upper bulkhead near the collar-side opening

These features create a force path:

```text
outer shell -> bulkheads -> dowel sleeve -> dowel rod
```

This should make the part more useful for a practice club than a plain hollow shell.

## Print Material

Preferred material:

```text
TPU
```

Reasons:

- impact tolerant
- flexible body feel
- suitable for dropped juggling props

## Print Orientation

Recommended first print orientation:

```text
standing vertically with the wide 58 mm side on the bed
```

This gives the shell its largest bed contact area.

## First Test Goals

The first print should answer:

- Does the hollow shell print cleanly in TPU?
- Is 2 mm wall thickness enough?
- Does 120 mm height print reliably?
- Does the taper feel reasonable for a club body?
- Does the 42 mm collar-side opening align visually with Part 5?

## Fusion Script Parameters

Use named variables in the script:

```python
wide_outer_diameter_mm = 58.0
collar_side_outer_diameter_mm = 42.0
wall_thickness_mm = 2.0
shell_height_mm = 120.0
dowel_diameter_mm = 12.7
dowel_clearance_mm = 0.5
dowel_sleeve_outer_diameter_mm = 20.0
lower_bulkhead_height_mm = 5.0
upper_bulkhead_height_mm = 5.0
edge_chamfer_mm = 0.5
```

Derived values:

```python
wide_inner_diameter_mm = wide_outer_diameter_mm - (wall_thickness_mm * 2)
collar_side_inner_diameter_mm = collar_side_outer_diameter_mm - (wall_thickness_mm * 2)
```

Fusion API note:

```text
Fusion internal length units are centimeters.
Convert mm to cm by dividing by 10.
```

## Open Questions

- Is 58 mm wide enough for the lower body?
- Is 120 mm a good first section height?
- Should wall thickness stay at 2 mm or increase for TPU?
- Should this part eventually include a socket, lip, or keyed joint for Part 5?
- Should centering ring stops be added inside the shell later?

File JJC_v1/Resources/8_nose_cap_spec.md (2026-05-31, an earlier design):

# Nose Cap Spec

## Purpose

The nose cap is the printed impact cap at the top end of the JJC V1 club. It protects the dowel end, closes the upper body shell, and gives the club a finished nose.

Reference diagram:

```text
Resources/Images/8_nose_cap_fit.svg
```

## Part Function

- Fits over the end of the 1/2 inch dowel rod
- Connects conceptually to the nose-side end of Part 7
- Protects the dowel end from impacts
- Finishes the top end of the club body

## Version 1 Geometry

Basic shape: short cylindrical TPU cap with a blind dowel socket

Suggested starting dimensions:

| Feature | Value | Notes |
| --- | ---: | --- |
| Outer diameter | 32 mm | Matches the nose-side outer diameter of Part 7 |
| Dowel socket diameter | 13.2 mm | 12.7 mm dowel plus 0.5 mm clearance |
| Cap height | 30 mm | First impact-cap test |
| Socket depth | 22 mm | Leaves 8 mm of solid TPU at the closed end |
| Closed end thickness | 8 mm | Impact material at nose tip |

## Dowel Fit

Use the same dowel clearance as the other dowel-fitting parts:

```text
1/2 inch dowel = 12.7 mm
clearance = 0.5 mm
socket diameter = 13.2 mm
```

The socket is blind, so the dowel does not pass all the way through the cap.

## Fit To Nearby Parts

The outer diameter should align with Part 7:

```text
Part 7 nose-side outer diameter = 32 mm
Part 8 outer diameter = 32 mm
```

This version does not include a locking joint yet.

## Print Material

Preferred material:

```text
TPU
```

Reasons:

- absorbs impacts
- protects the dowel end
- consistent with the body and handle parts

## Print Orientation

Recommended first print orientation:

```text
closed nose end on the XY plane, socket opening upward
```

This gives the cap a solid base on the print bed and avoids support inside the dowel socket.

## First Test Goals

The first print should answer:

- Does the socket fit the dowel?
- Does the 32 mm diameter align visually with Part 7?
- Is 8 mm enough closed-end material for impact protection?
- Does the cap feel too small, too large, or about right?

## Fusion Script Parameters

Use named variables in the script:

```python
outer_diameter_mm = 32.0
dowel_diameter_mm = 12.7
dowel_clearance_mm = 0.5
cap_height_mm = 30.0
socket_depth_mm = 22.0
```

Derived values:

```python
socket_diameter_mm = dowel_diameter_mm + dowel_clearance_mm
closed_end_thickness_mm = cap_height_mm - socket_depth_mm
```

Fusion API note:

```text
Fusion internal length units are centimeters.
Convert mm to cm by dividing by 10.
```

## Open Questions

- Should the nose cap become more rounded in a later version?
- Should the nose cap overlap Part 7 instead of just matching its diameter?
- Should the socket be glued to the dowel or remain removable?
- Is 30 mm a good cap height for practice juggling?

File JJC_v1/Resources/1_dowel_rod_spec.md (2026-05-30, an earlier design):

# Dowel Rod Spec

## Purpose

The dowel rod is the rigid center spine of the JJC V1 juggling club. Printed parts are designed to slide over, grip, or align around this rod.

## Recommended V1 Size

Use a 1/2 inch dowel rod for the first prototype.

```text
1/2 inch = 12.7 mm
```

Recommended design value:

```text
dowel diameter = 12.7 mm
```

## Why 1/2 Inch

A 1/2 inch dowel is a good first choice because it is:

- easy to find
- stiff enough for a first club prototype
- not excessively heavy
- large enough to design printed sleeves and rings around
- simple to measure and replace

## Material

Recommended first material:

```text
hardwood dowel
```

Possible later alternatives:

- fiberglass rod
- carbon fiber tube or rod
- aluminum tube

For V1, use a simple hardwood dowel unless there is a clear reason to change.

## Measurement Requirement

Measure the actual dowel with calipers before finalizing printed parts.

Even if the dowel is sold as 1/2 inch, the actual diameter may vary slightly.

Record:

```text
measured dowel diameter = ____ mm
```

Use the measured value in Fusion scripts instead of assuming exactly 12.7 mm.

## Printed-Part Clearance

For parts that slide over the dowel, use:

```text
hole diameter = measured dowel diameter + clearance
```

Suggested first clearance for TPU:

```text
0.5 mm total clearance
```

Example using nominal 1/2 inch dowel:

```text
12.7 mm dowel + 0.5 mm clearance = 13.2 mm hole
```

## Length

The final dowel length depends on the final club length.

For the first design phase, model the dowel as a reference cylinder running through:

- knob cap
- handle sleeve
- body-to-handle collar
- body shell
- nose cap

Leave final length open until the overall club proportions are chosen.

## Open Questions

- What is the actual measured dowel diameter?
- What total club length should V1 target?
- Should the dowel run all the way into the nose cap?
- Should printed parts be removable from the dowel or permanently bonded?
- Should the dowel be wood for V1 or should we move to a tube/rod material later?

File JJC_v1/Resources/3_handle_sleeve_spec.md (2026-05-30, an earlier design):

# Handle Sleeve Spec

## Purpose

The handle sleeve is the printed grip section that slides over the dowel rod. It gives the club a larger, more comfortable handle while using the dowel as the rigid center spine.

Reference diagram:

```text
Resources/Images/3_handle_sleeve_fit.svg
```

## Part Function

- Slides over the 1/2 inch dowel rod
- Provides the main hand grip area
- Adds diameter around the dowel without needing a solid printed handle
- Tests a longer TPU sleeve fit before designing the full club body

## Version 1 Geometry

Basic shape: hollow tube

Suggested starting dimensions:

| Feature | Value | Notes |
| --- | ---: | --- |
| Outer diameter | 24 mm | First grip-size test |
| Inner diameter | Dowel diameter + clearance | Matches the dowel centering ring hole |
| Length | 80 mm | Short enough for a first print, long enough to test grip feel |
| Edge treatment | Small chamfer | Helps the sleeve slide onto the dowel |

## Dowel Fit

Use the same starting clearance as the dowel centering ring:

```text
1/2 inch dowel = 12.7 mm
clearance = 0.5 mm
inner diameter = 13.2 mm
```

This should be a slip fit for TPU. If the sleeve is too loose, reduce clearance. If it is too tight, increase clearance.

## Print Material

Preferred material:

```text
TPU
```

Reasons:

- comfortable grip feel
- impact tolerant
- can flex slightly over the dowel

## Print Orientation

Recommended first print orientation:

```text
standing vertically on one end
```

Benefits:

- cleaner circular hole
- no support needed for a straight tube
- tests whether the printer handles a taller TPU sleeve well

If vertical TPU printing is unstable, test a shorter sleeve length before changing the part design.

## First Test Goals

The first print should answer:

- Does the sleeve slide onto the dowel?
- Is the grip diameter comfortable?
- Is 80 mm a useful test length?
- Does TPU print cleanly as a vertical tube?
- Does the sleeve twist or wobble on the dowel?

## Fusion Script Parameters

Use named variables in the script:

```python
outer_diameter_mm = 24.0
dowel_diameter_mm = 12.7
dowel_clearance_mm = 0.5
sleeve_length_mm = 80.0
edge_chamfer_mm = 0.75
```

Derived value:

```python
inner_diameter_mm = dowel_diameter_mm + dowel_clearance_mm
```

Fusion API note:

```text
Fusion internal length units are centimeters.
Convert mm to cm by dividing by 10.
```

## Open Questions

- Is 24 mm a comfortable grip diameter?
- Should the handle sleeve be one long piece or several shorter grip sections?
- Should the outside eventually have grooves, ribs, or a textured grip?
- Should the sleeve be removable or bonded to the dowel?

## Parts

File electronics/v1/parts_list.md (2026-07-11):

# v1 Parts List

| Item | Qty | Description | Suggested Part | Purchase Link | Notes |
|---|-----|---|---|---|---|
| Microcontroller | 1 | Programmable embedded board | ESP32 dev board, Gold Edition, Type-C | https://www.amazon.com/dp/B0FRXZD6VC | Compatible with Arduino IDE, MicroPython, and ESP-IDF |
| LED strip | 1 roll | Addressable RGB LEDs for prototyping | WS2812B 5m strip, 300 LEDs | https://www.amazon.com/dp/B097BWJGYK | Cut or connect only a short section for initial tests |
| Power | 1 | 5V power source | 5V USB or bench power supply | https://www.amazon.com/s?k=5v+usb+power+supply | Size the supply for the LED count; share ground with ESP32 |
| Bulk capacitor | 1 pack | Power smoothing | ALLECIN 1000 uF 10V electrolytic capacitor pack | https://www.amazon.com/dp/B0CMQCC5D3 | Use one capacitor per LED power input; observe polarity |
| Series resistor | 1 kit | Data line protection | BOJACK 1/4W resistor assortment with 330 ohm values | https://www.amazon.com/dp/B08FD1XVL6 | Use one 330 ohm resistor per LED data line |
| Logic level shifter | 1 | Data signal reliability | 74AHCT125 / SN74AHCT125 3.3V-to-5V level shifter | https://www.adafruit.com/product/1787 | Recommended for WS2812B when using ESP32 3.3V data |
| Data wire | 1 kit | Signal and power wiring | 22 AWG silicone wire, multiple colors | https://www.amazon.com/s?k=22+awg+silicone+wire | Flexible and solderable |
| Connectors | 1 pack | Optional USB 5V/GND power access | Jienk 22 AWG USB-A male 2-pin power pigtail, 5 pack | https://www.amazon.com/dp/B0CRQTYV9H | Optional for bench setup; use only 5V and GND |
| Soldering | 1 kit | Tools | Soldering iron and solder | https://www.amazon.com/s?k=soldering+iron+kit | Required if you do not already have soldering tools |
| Insulation | 1 kit | Wire protection | Ginsco 580-piece 2:1 heat shrink tubing kit | https://www.amazon.com/dp/B01MFA3OFA | Protects solder joints; assorted sizes are useful for wire and connector joints |
| Optional | 1 kit | Button input | 120-piece 12x12x7.3 mm momentary tactile button kit with caps | https://www.amazon.com/dp/B0G2CRKZ4G | Later for manual color change; use one button for the first prototype |
| Optional | 1 pack | Motion sensor | KEAcvise 6-pack GY-521 MPU6050 6-axis accelerometer/gyroscope modules | https://www.amazon.com/dp/B0F9DLNHTB | Future motion detection prototype; uses one I2C module and keeps spares |

## Power Notes

The 5m WS2812B strip has 300 LEDs. At full white and full brightness, that can draw far more current than a computer USB port or small USB wall adapter can safely supply.

For first tests:

- Cut or connect only a short section, such as 8-16 LEDs.
- Keep brightness low in software.
- Power the LEDs from a 5V supply sized for the LED count.
- Always connect ESP32 GND and LED power supply GND together.

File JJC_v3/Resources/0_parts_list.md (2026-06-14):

# JJC V3 Parts List

Goal: create a hollow-body juggling club that keeps the V2 Delphin-style length and handle proportions, but lowers the estimated center of rotation by reducing upper-body mass and using a hollow slip-jointed body.

## Balance Target

```text
Overall length: 502 mm
Target balance point: 255-265 mm from knob end
Target balance ratio: 51-53% of total length
Estimated V3 balance point: 260.6 mm from knob end
Estimated V3 balance ratio: 51.9%
Estimated V3 mass: 266.1 g
```

## Parts

### 1. Dowel Rod

Rigid 1/2 inch hardwood spine.

### 2. Knob Cap

Handle-end bumper and lower counterweight.

### 3. Handle Sleeve

Long tapered grip sleeve.

### 4. Handle-to-Body Collar

Transition from handle diameter to lower body diameter.

### 5. Lower Hollow Body Shell

Closed bottom, open top, and male slip lip that slides into Part 6.

### 6. Upper Hollow Body Shell

Open bottom receiving socket and closed top near the nose.

### 7. Nose Cap

Compact top impact cap.

## Numbering Note

V3 follows the V2 numbering pattern:

```text
Part 5 = lower body shell
Part 6 = upper body shell
Part 7 = nose cap
```

Earlier V3 discussion referred to the two hollow shells as Parts 6 and 7. In this resource set, those same hollow shell ideas are documented as Parts 5 and 6 so V3 remains directly comparable to V2.

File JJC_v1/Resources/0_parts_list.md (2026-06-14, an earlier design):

# JJC V1 Parts List

Goal: design a simple printable juggling club for Jordan's Juggle Clubs around a dowel rod spine. This version does not include LEDs, electronics, or diffuser parts.

## Printer Constraints

- Printer: Creality Ender 3 V3 SE
- Build volume: 220 x 220 x 250 mm
- Planned material: mostly TPU
- Design assumption: the full club will be printed in sections

## Estimated Balance

V1 is an early prototype and does not lock the final dowel length. Using the first-test stacked part dimensions documented in these specs:

```text
Estimated prototype length: 413 mm
Hardwood dowel density assumption: 0.70 g/cm^3
TPU/plastic density assumption: 1.20 g/cm^3
Estimated V1 prototype mass: 314.1 g
Estimated V1 prototype balance point: 209.1 mm from knob end
Estimated V1 prototype balance ratio: 50.6% of prototype length
```

This is an estimate only. V1 was meant to test part fit and printability, not final juggling balance.

## Parts

### 1. Dowel Rod

- Purpose: main rigid spine along the club axis
- Runs through the handle and body
- Printed parts should slide over or mount around it
- Exact diameter should be measured before finalizing hole sizes

### 2. Dowel Centering Ring

- Priority: first part to design and print
- Purpose: keeps the dowel centered inside the hollow club body
- Shape: washer-like ring
- Good first test because it is small, fast, and checks dowel fit

### 3. Handle Sleeve

- Purpose: grip surface around the dowel
- Likely material: TPU
- Can be one sleeve or several shorter grip sections

### 4. Knob Cap

- Purpose: rounded end cap at the handle end
- Likely material: TPU
- Should protect the dowel end and take drops

### 5. Body-to-Handle Collar

- Purpose: transition from the narrow handle to the wider club body
- Likely material: TPU
- Helps define the club shape and supports the lower body shell

### 6. Lower Body Shell

- Purpose: lower half of the hollow club body
- Likely material: TPU
- Designed around the dowel and centering rings

### 7. Upper Body Shell

- Purpose: upper half of the hollow club body
- Likely material: TPU
- Connects to the lower body shell and nose cap

### 8. Nose Cap

- Purpose: rounded top cap of the club
- Likely material: TPU
- Should be replaceable if it gets damaged

### 9. Section Couplers

- Purpose: align and connect printed shell sections
- Could be slip-fit rings, threaded sleeves, or simple keyed joints
- Material can be TPU or a stiffer filament depending on the fit needed

## Suggested Build Order

1. Buy and measure the dowel rod
2. Dowel centering ring
3. Handle sleeve test
4. Knob cap
5. Short hollow body shell test
6. Body-to-handle collar
7. Upper/lower body shell sections
8. Nose cap
9. Section couplers

## First Print Recommendation

Start with the dowel centering ring. It will test:

- Fusion scripting workflow
- dowel fit
- printer dimensional accuracy
- TPU flexibility
- how much clearance the dowel needs

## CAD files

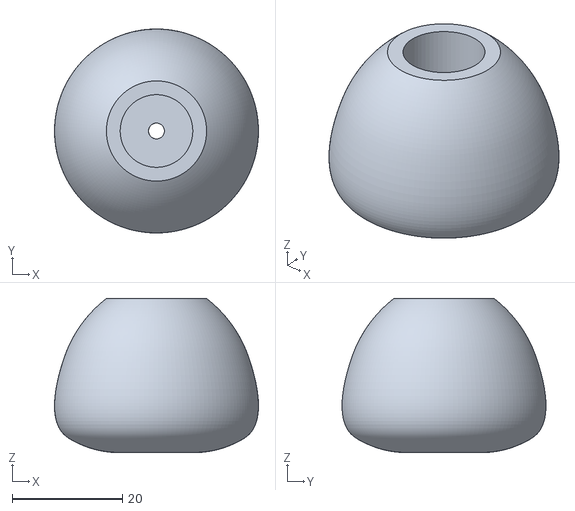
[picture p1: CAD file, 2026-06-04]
JJC_v3/Fusion/JJCv3_2_knob_cap/JJCv3_2_knob_cap.stl
37.1 x 37.0 x 28.0

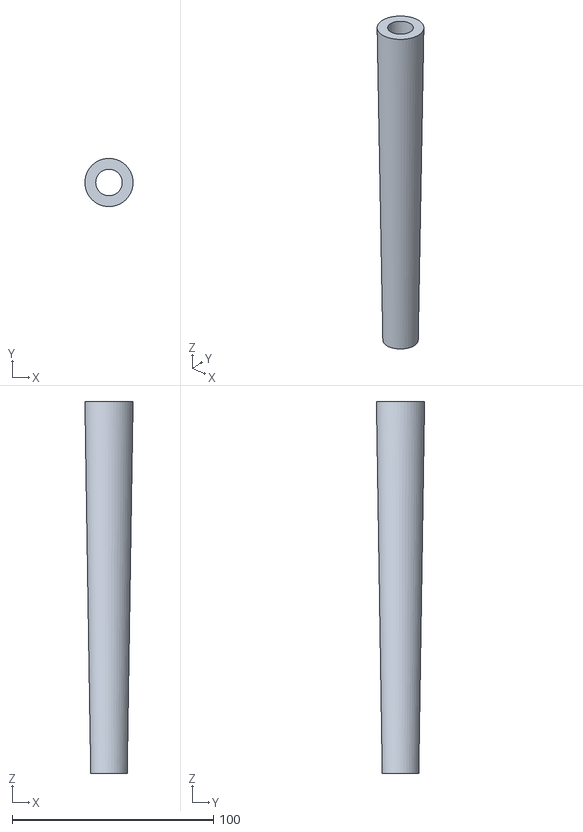
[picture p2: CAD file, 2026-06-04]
JJC_v3/Fusion/JJCv3_3_handle_sleeve/JJCv3_3_handle_sleeve.stl
24.0 x 24.0 x 185.0

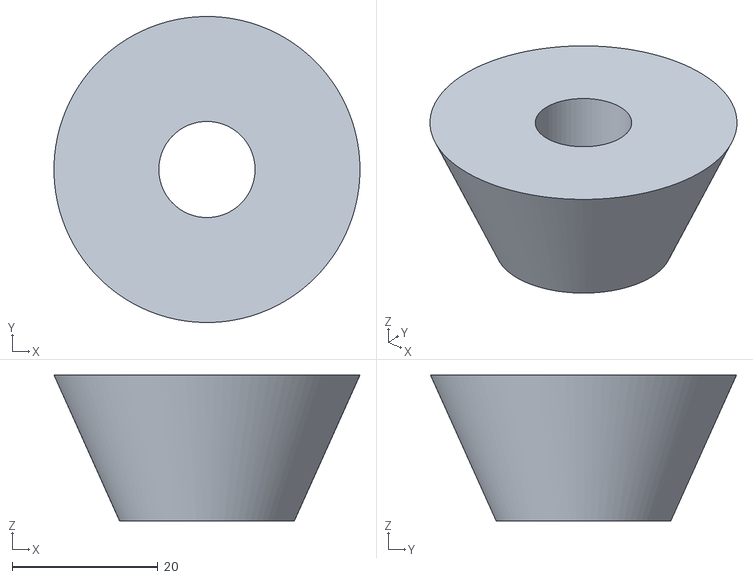
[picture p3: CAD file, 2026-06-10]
JJC_v3/Fusion/JJCv3_4_handle_to_body_collar/JJCv3_4_handle_to_body_collar.stl
42.0 x 42.0 x 20.0

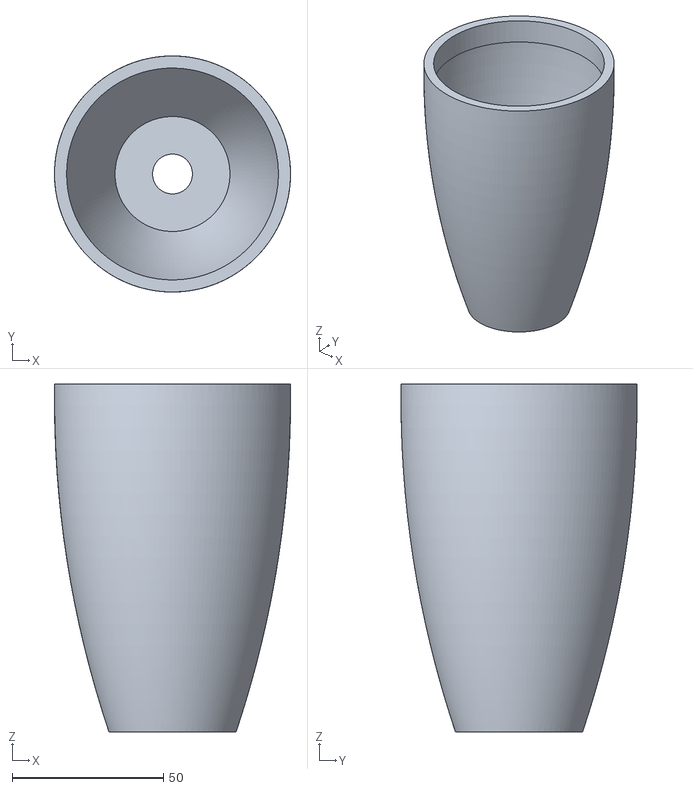
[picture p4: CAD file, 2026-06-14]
JJC_v3/Fusion/JJCv3_5_lower_body_shell/JJCv3_5_lower_body_shell.stl
78.0 x 78.0 x 115.0

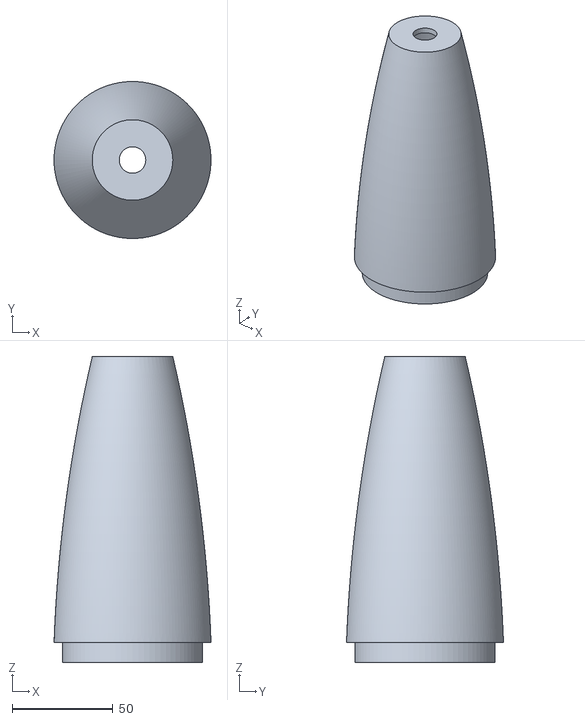
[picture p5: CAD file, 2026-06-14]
JJC_v3/Fusion/JJCv3_6_upper_body_shell/JJCv3_6_upper_body_shell.stl
78.0 x 78.0 x 152.0

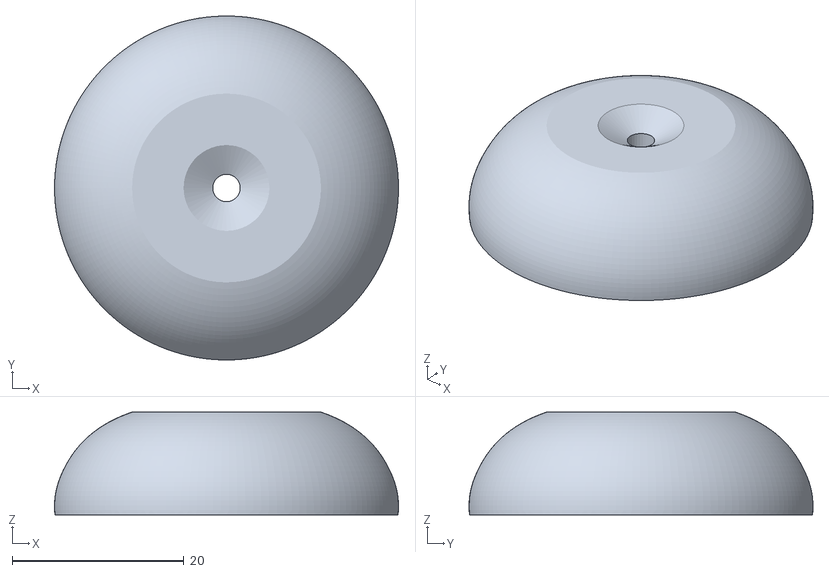
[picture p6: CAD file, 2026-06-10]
JJC_v3/Fusion/JJCv3_7_nose_cap/JJCv3_7_nose_cap.stl
40.1 x 40.1 x 12.0

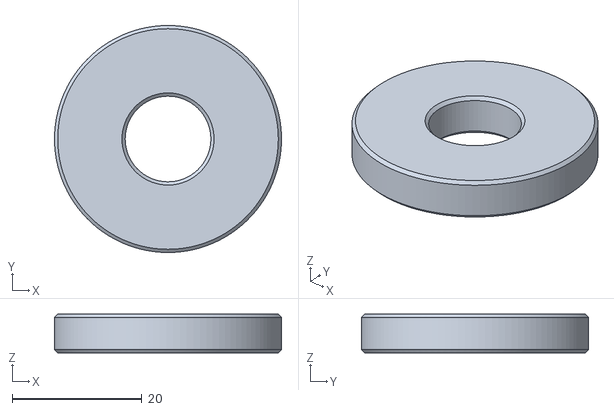
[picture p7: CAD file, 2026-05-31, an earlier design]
JJC_v1/Fusion/JJCv1_2_dowel_centering_ring/JJCv1_2_dowel_centering_ring.stl
35.0 x 35.0 x 6.00

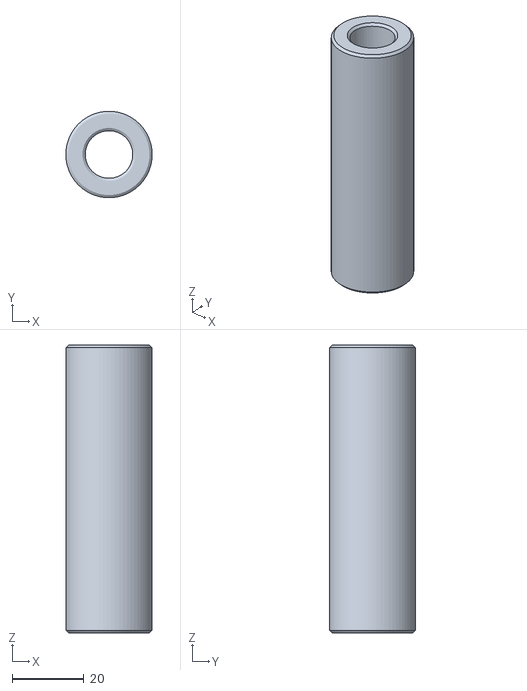
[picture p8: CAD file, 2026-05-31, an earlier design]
JJC_v1/Fusion/JJCv1_3_handle_sleeve/JJCv1_3_handle_sleeve.stl
24.0 x 24.0 x 80.0

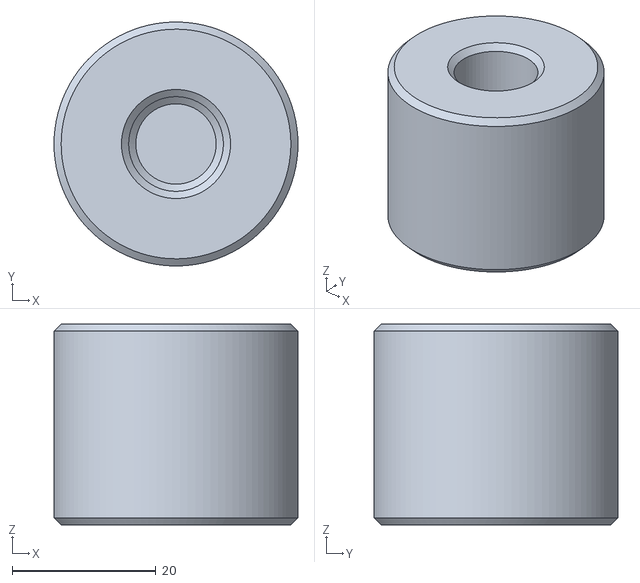
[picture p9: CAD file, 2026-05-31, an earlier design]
JJC_v1/Fusion/JJCv1_4_knob_cap/JJCv1_4_knob_cap.stl
34.0 x 34.0 x 28.0

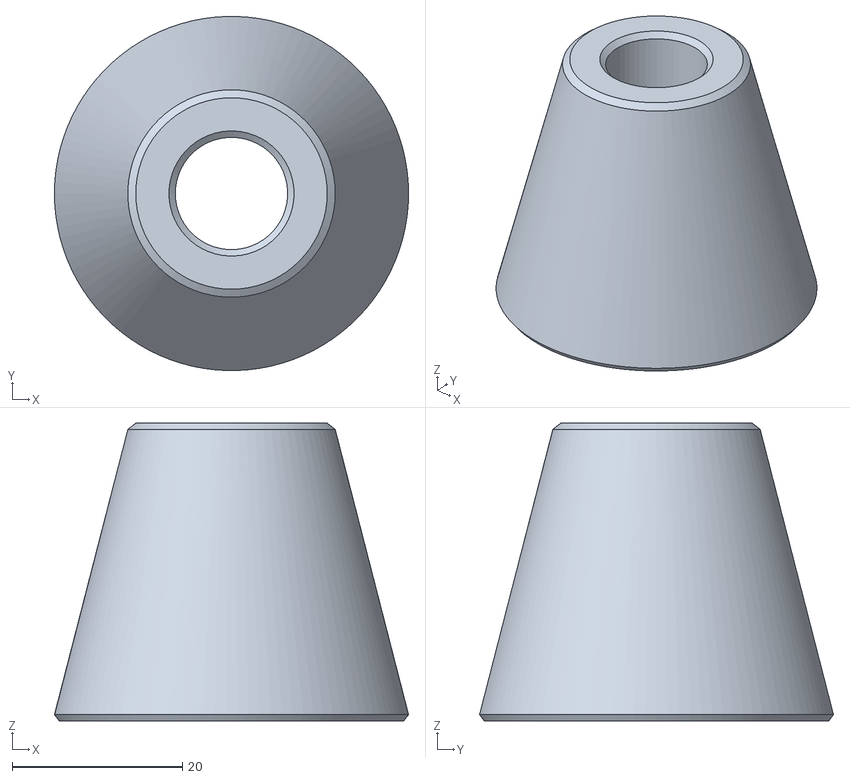
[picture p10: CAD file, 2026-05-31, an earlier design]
JJC_v1/Fusion/JJCv1_5_body_to_handle_collar/JJCv1_5_body_to_handle_collar.stl
41.6 x 41.6 x 35.0

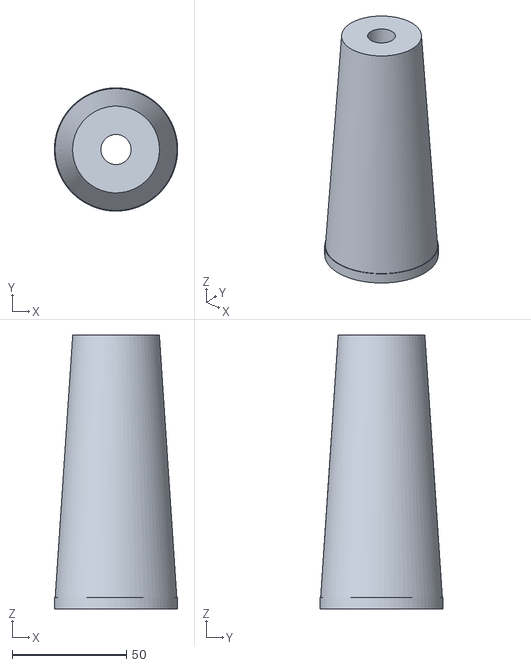
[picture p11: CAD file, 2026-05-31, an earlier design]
JJC_v1/Fusion/JJCv1_6_lower_body_shell/JJCv1_6_lower_body_shell.stl
54.0 x 54.0 x 120.0

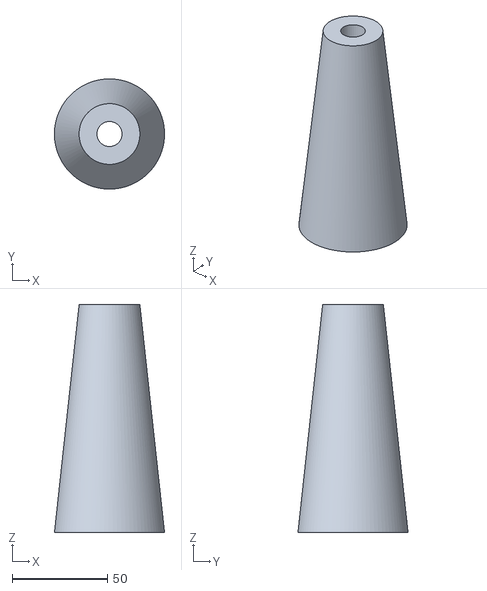
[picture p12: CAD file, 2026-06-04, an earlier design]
JJC_v1/Fusion/JJCv1_7_upper_body_shell/JJCv1_7_upper_body_shell_modified.stl
58.0 x 58.0 x 120.0

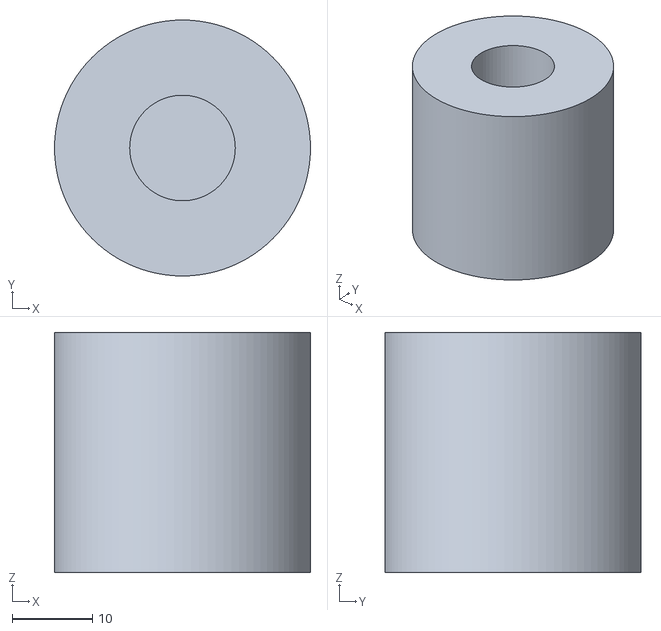
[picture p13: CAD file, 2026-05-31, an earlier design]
JJC_v1/Fusion/JJCv1_8_nose_cap/JJCv1_8_nose_cap.stl
32.0 x 32.0 x 30.0

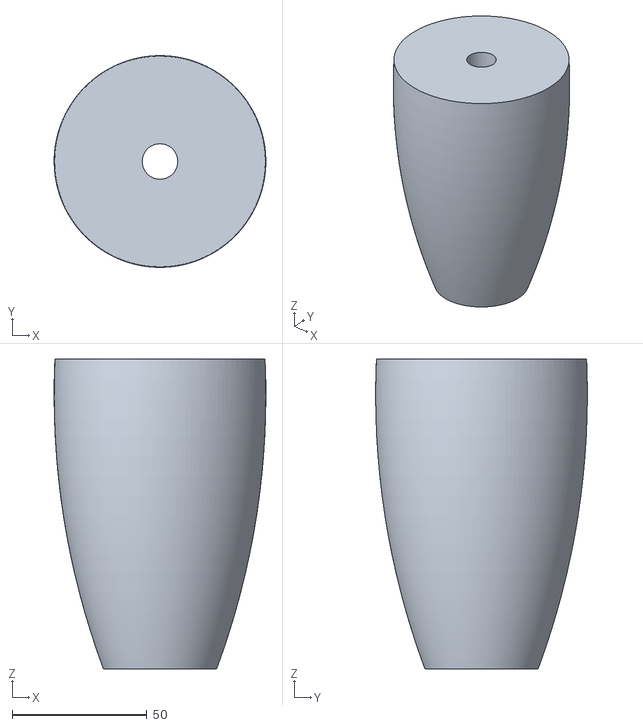
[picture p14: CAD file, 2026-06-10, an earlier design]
JJC_v2/Fusion/JJCv2_5_lower_body_shell/JJCv2_5_lower_body_shell.stl
78.6 x 78.6 x 115.0

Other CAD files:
JJC_v2/Fusion/JJCv2_2_knob_cap/JJCv2_2_knob_cap.stl
JJC_v2/Fusion/JJCv2_6_upper_body_shell/JJCv2_6_upper_body_shell.stl
JJC_v1/Fusion/JJCv1_7_upper_body_shell/JJCv1_7_upper_body_shell.stl
JJC_v3/Fusion/JJCv3_6_upper_body_shell/JJCv3_6_upper_body_shell.f3d

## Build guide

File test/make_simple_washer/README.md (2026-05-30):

# Simple Washer Fusion Script

This folder contains a small Autodesk Fusion Python script that creates a simple washer from two sketch circles and an extrusion.

## Run The Script

1. Open Autodesk Fusion.
2. Create a new design.
3. Switch to the **Utilities** tab.
4. Open **Add-Ins > Scripts and Add-Ins**.
5. Select the **Scripts** tab.
6. If `make_simple_washer` is listed, select it.
7. If it is not listed, click the green **+** button and add this folder:

   ```text
   test/make_simple_washer
   ```

8. Click **Run**.

The script pauses with message boxes after each major step so you can inspect Fusion before continuing.

## Debug In VS Code

1. In Fusion, open **Utilities > Add-Ins > Scripts and Add-Ins**.
2. Select `make_simple_washer`.
3. Click **Edit** to let Fusion open the script in VS Code.
4. In VS Code, set breakpoints in `make_simple_washer.py`.
5. Start the **Python: Attach** debug configuration.
6. Run the script from Fusion.

If VS Code says **connection refused**, Fusion's debug listener is probably not running. Reopen the script from Fusion with **Edit**, then try attaching again.

To check whether anything is listening on port `9000`:

```powershell
Get-NetTCPConnection -LocalPort 9000 -ErrorAction SilentlyContinue |
  Select-Object LocalAddress,LocalPort,State,OwningProcess
```

If no row appears, Fusion is not listening on that port.

## Browser Notes

Fusion does not provide a scriptable API or preference to auto-expand the main Browser tree folders like **Sketches** and **Bodies**.

For this learning script:

1. When the script pauses after creating the sketch, manually expand **Sketches** in the Browser.
2. After the extrusion creates the washer, manually expand **Bodies** if Fusion leaves it collapsed.
3. Watch the canvas selection as well as the Browser. The script selects each object as it creates it.

## Units

Fusion API length values are in centimeters.

```python
outer_diameter = 4.0   # 40 mm
inner_diameter = 1.5   # 15 mm
thickness = 0.3        # 3 mm
```

Change those values to resize the washer.

## Common Debugger Quirk

After the script finishes, VS Code may open a tab named `<string>` with a message like:

```text
Could not load source '<string>'
```

That usually means the debugger tried to step into Fusion's internal script wrapper after your script returned. If the washer was created and Fusion did not show a traceback from the script, this is just debugger noise. Press **Continue** or stop debugging.

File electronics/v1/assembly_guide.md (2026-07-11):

# ESP32 Electronics Assembly Guide

This guide shows how to assemble the ESP32-based LED prototype once your parts arrive.
It is written for the parts in `electronics/v1/parts_list.md`.

Reference diagram:

```text
electronics/v1/wiring_diagram_basic_led_test.svg
```

## 1. Check Your Parts

- ESP32 dev board
- WS2812B NeoPixel-style strip, starting with 8-16 LEDs
- 5V power supply sized for the number of LEDs connected
- 22 AWG silicone wire or jumper wires
- Logic level shifter, 3.3V to 5V, for the LED data line
- 1000 uF capacitor, 10V or higher
- 330 ohm resistor
- Optional: small tactile button, motion sensor
- Soldering tools, heat shrink tubing, multimeter

## 2. Prepare The LED Strip

- Cut the strip to the number of LEDs you want.
- Tin the +5V, GND, and DIN pads lightly with solder.
- If the strip has a direction arrow, the arrow should point from the controller toward the LEDs.

## 3. Wiring Overview

### Required Connections

- **5V power**
  - Connect the 5V supply to the LED strip +5V pad.
  - Connect the same 5V supply to the ESP32 VIN or 5V pin, not the 3.3V pin.
- **Ground**
  - Connect LED strip GND to ESP32 GND.
  - Use a common ground for all devices.
- **Data**
  - Connect ESP32 GPIO pin to the logic level shifter input.
  - Connect the shifter output to the LED strip DIN pad.

### Recommended Protection

- Put a 1000 uF electrolytic capacitor across 5V and GND at the beginning of the LED strip.
- Add a 330 ohm resistor in series with the LED data line between the level shifter and DIN.
- Use a logic level shifter because ESP32 outputs 3.3V and the strip is powered at 5V.

### Example Pin Choices

- `DATA_PIN = 5` or another safe ESP32 GPIO
- `5V` power to VIN / 5V pin
- `GND` to GND

Confirm the raw GPIO number for your exact board before wiring.

## 4. Assembly Steps

1. Place the ESP32 board and LED strip near each other.
2. Run two power wires: one for 5V and one for GND.
3. Connect the LED strip +5V to the power rail and GND to the common ground.
4. Connect ESP32 VIN/5V to the same 5V supply.
5. Connect ESP32 GND to common ground.
6. Connect ESP32 data pin to the logic shifter input.
7. Connect the logic shifter output to LED strip DIN.
8. Add the 330 ohm resistor in series with the data output.
9. Add the 1000 uF capacitor across 5V and GND at the strip.
10. Double-check all connections before powering up.

Do not power a full 300-LED strip from the ESP32 board or a normal computer USB port. Start with a short LED section and low brightness until the 5V supply is sized for the number of LEDs connected.

## 5. Test Before Final Installation

- Use the Arduino IDE to upload the test script from `esp32_programming.md`.
- After upload, power the board and watch the LED strip.
- If nothing lights, verify:
  - 5V is present at the strip
  - Ground is common
  - Data pin is correct
  - Direction on the strip is correct

## 6. Mounting In The Club

- Keep the ESP32 and wiring away from moving parts.
- Secure the LED strip flat inside the club body where it will be visible.
- Put the board in a location where USB access is possible for later updates.
- Use heat shrink or tape to protect solder joints.

## 7. Next Steps

- Program the ESP32 with the baseline test sketch.
- Confirm the LED strip turns on and cycles colors.
- Once the test works, move to the full lighting behavior script.

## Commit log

2026-05-31 added Fusion script files
    [JJCv1_2_dowel_centering_ring.stl, JJCv1_3_handle_sleeve.stl, JJCv1_4_knob_cap.stl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]
2026-06-04 v2 added
    [JJCv1_7_upper_body_shell_modified.stl, JJCv2_2_knob_cap.stl, JJCv2_2_knob_cap_correct.stl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]
2026-06-10 modified v2
    [JJCv2_4_handle_to_body_collar.stl, JJCv2_5_lower_body_shell.stl, JJCv2_6_upper_body_shell.stl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]
2026-06-14 Added V3
    [JJCv3_2_knob_cap.stl, JJCv3_3_handle_sleeve.stl, JJCv3_4_handle_to_body_collar.stl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]
2026-07-11 adding wiring diagram
